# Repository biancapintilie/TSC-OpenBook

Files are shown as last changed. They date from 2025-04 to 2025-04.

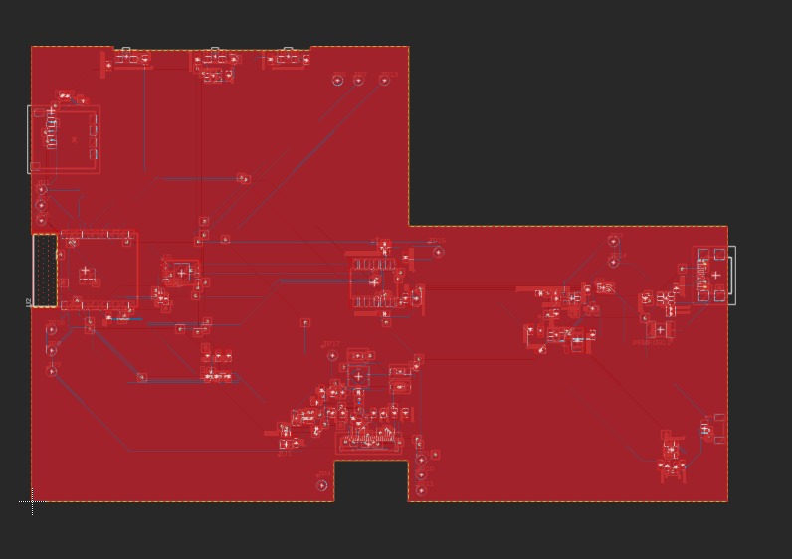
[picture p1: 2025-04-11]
Images/openbook_pcb_top.jpg

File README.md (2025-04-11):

# OpenBook

## Descriere
OpenBook este un dispozitiv portabil bazat pe microcontrollerul ESP32-C6, proiectat pas cu pas, incepand cu schema componentelor, apoi schema electrica si in final modelul 3D al acestuia, urmarind schemele si indrumarile oferite in enuntul temei.
Pentru schematic am descarcat libraria din enunt si am folosit piesele de acolo pentru a realiza componentele si le-am asezat in frame exact ca in exemplul din enunt.
La partea de PCB am amplasat piesele dupa desenul dat, urmand masuratorile exacte, iar rutarea am facut-o folosind combinatia intre autorute si rute manuale pentru evitarea erorilor, fiind nevoita sa mai misc piesele incat sa pot ruta cat mai ok. Apoi am facut planurile de masa, atat pentru top cat si pentru bottom.
In final, am cautat modelul 3D pentru fiecare piesa pentru a-l adauga la forma 3D finala a dispozitivului, impreuna cu carcasa acestuia.

## Hardware

### **1. Microcontroller U2 – ESP32-C6-WROOM-1-N8**
#### - Modul principal de procesare, cu:
 - Procesor RISC-V single-core, 160 MHz
 - 	Wi-Fi 6 și Bluetooth 5.0
 - 	8 MB flash
 - 	Alimentare: 3.3V
#### - Conexiuni principale:
- SPI (pentru e-paper și microSD)
- I2C (pentru RTC și senzori)
- GPIO (pentru butoane, LED-uri, control power)

#### - Pini folosiți ESP32-C6:
| Semnal | Pin ESP32	| Funcție |
|---|---|---|
| MOSI | GPIO10 |	Date spre e-paper |
| SCK | GPIO9 |	Ceas SPI |
| CS | GPIO8 | Chip Select |
| DC | GPIO7 | Data/Command |
| RST | GPIO5 |	Reset display |
| BUSY | GPIO6 | Status afișaj |

### 2. Afișaj e-paper J1 – FH34SRJ-24S-0.5SH
- Afișaj conectat prin SPI
- Condensatori de filtrare în jurul e-paper:
- EPD_C1–C12: 0.1–1uF (filtrare alimentare și stabilizare semnal)
- MOSFET: Q3 – SI1308EDL (pentru comutarea alimentării e-paperului)

### 3. Memorie și stocare U1 – W25Q512JVEIQ
- 64MB NOR Flash SPI
- Pentru stocarea fișierelor locale, fonturi, etc.
microSD (SPI shared):
- Partajat cu SPI-ul e-paper
- CS separat (ex: GPIO15)

### 4. Alimentare & management baterie Li-Po 3.7V
#### - Încărcare:
- MCP73831 (U MCP73831) – încărcare baterie prin USB
- Diodă protecție: D3–D5 (MBR0530)
#### - Monitorizare baterie:
- MAX17048 (U4) – Fuel Gauge via I2C
- Divizor rezistiv: R1_BAT, R2_BAT
- ADC ESP32: GPIO1
#### - Condensatori alimentare:
- C1_BAT, C2_BAT, C3, etc. – diverse capacități pentru filtrare și stabilizare (4.7uF – 100uF)

### 5. Ceas în timp real (RTC) U3 – DS3231SN
- RTC cu I2C, extrem de precis
- Backup pe supercapacitor (C10_SUPERCAP)
- Conexiune I2C: GPIO21 (SDA), GPIO22 (SCL)

### 6. Senzor SENSOR2 – BME680
- Senzor de mediu: temperatură, presiune, umiditate, COV
- Interfață I2C (partajat cu RTC)

### 7. Interfață utilizator
#### - Butoane fizice:
- BOOT_BUTTON, RESET_BUTTON, CHANGE_BUTTON
- Conectate pe GPIO2, GPIO3, GPIO4 (cu pull-up R_RESET, R_CHANGE etc.)
#### - LED RGB pentru feedback:
- CHG_LED – conectat la GPIO18 (PWM)

### 8. Protecție și filtrare
- D1 – USBLC6-2SC6Y – protecție ESD pe linia USB
- PGB1010603MR (D6, D8–D12) – protecție la supratensiune
- PFMF.050.1 – Varistor pentru liniile de alimentare

### 9. Alte circuite pasive
- Filtru LC pe alimentare display: L1 – 68uH, C7, C8
- Diverse rezistențe pull-up/down, limitare curent, etc.:
- R1–R10, R_BOOT, R_PWRUSB, R_CAPACITOR etc.
- Majoritatea în format 0402

### 10. Test Points & Debug
- TP1–TP17: puncte de test pentru semnale critice
- UART debug: GPIO43 (TX), GPIO44 (RX) – pentru încărcare firmware și debug

### Carcasă și design fizic
- PCB în format compact, optimizat pentru portabilitate
- Carcasă printată 3D
- Acces facil la conectorul USB-C (J2) pentru încărcare

## Schema Bloc


## Bill Of Materials

| Componenta | Link | Datasheet |
|---|---|---|
| Capacitor 0402 | [Model](https://componentsearchengine.com/part-view/CC0402MRX5R5BB106/YAGEO) | [Datasheet](https://componentsearchengine.com/Datasheets/2/CC0402MRX5R5BB106.pdf) |
| CPH3225A | [Model](https://www.snapeda.com/parts/CPH3225A/Seiko+Instruments/view-part/?ref=eda) | [Datasheet](https://www.snapeda.com/parts/CPH3225A/Seiko+Instruments/view-part/?ref=eda) |
| RCL 3528 | [Model](https://www.snapeda.com/parts/TAJB475K025RNJ/AVX/view-part/?ref=dk&t=capacitor%203528&con_ref=None) | [Datasheet](https://s3.amazonaws.com/snapeda/datasheet/TAJB475K025RNJ_AVX.pdf) |
| Resistor 0402 | [Model](https://componentsearchengine.com/part-view/R0402%201%25%20100%20K%20(RC0402FR-07100KL)/YAGEO) | [Datasheet](https://www.yageo.com/upload/media/product/products/datasheet/rchip/PYu-RC_Group_51_RoHS_L_12.pdf) |
| Dioda MBR0530 | [Model](https://eu.mouser.com/ProductDetail/KYOCERA-AVX/SD0805S020S1R0?qs=jCA%252BPfw4LHbpkAoSnwrdjw%3D%3D) | [Datasheet](https://ro.mouser.com/datasheet/2/40/schottky-3165252.pdf) |
| Dioda PGB1010603MR | [Model](https://www.snapeda.com/parts/PGB1010603MR/Littelfuse/view-part/?ref=eda) | [Datasheet](https://www.snapeda.com/parts/PGB1010603MR/Littelfuse%20Inc./datasheet/) |
| Buton | [Model](https://industry.panasonic.com/global/en/products/control/switch/light-touch/number/evqpuj02k) | [Datasheet](https://industry.panasonic.com/global/en/downloads?tab=catalog&small_g_cd=203&part_no=EVQPUJ02K) |
| LED 0603 | [Model](https://www.snapeda.com/parts/KP-1608SURCK/Kingbright/view-part/?ref=search&t=LED%200603) | [Datasheet](https://www.snapeda.com/parts/KP-1608SURCK/Kingbright/datasheet/) |
| Sensor BME680 | [Model](https://www.digikey.ro/en/models/7401317) | [Datasheet](https://www.bosch-sensortec.com/media/boschsensortec/downloads/datasheets/bst-bme680-ds001.pdf) |
| SJ | [Model](https://grabcad.com/library/solder-jumpers-1) | [Datasheet](https://grabcad.com/library/solder-jumpers-1) |
| ESP32C6 | [Model](https://ro.mouser.com/ProductDetail/EPCOS-TDK/B72520T0350K062?qs=dEfas%2FXlABIszF52uu7vrg%3D%3D) | [Datasheet](https://www.snapeda.com/parts/RC0603JR-070RL/Yageo/datasheet/) |
| FH34SRJ-24S-0.5SH (J1) | [Model](https://www.snapeda.com/parts/FH34SRJ-24S-0.5SH(99)/Hirose/view-part/) | [Datasheet](https://www.snapeda.com/parts/FH34SRJ-24S-0.5SH(99)/Hirose%20Connector/datasheet/) |
| USB4110-GF-A (J2) | [Model](https://componentsearchengine.com/part-view/USB4110-GF-A/GCT%20(GLOBAL%20CONNECTOR%20TECHNOLOGY)) | [Datasheet](https://gct.co/files/drawings/usb4110.pdf) |
| QWIIC Connector (J3) | [Model](https://www.snapeda.com/parts/PRT-14417/SparkFun/view-part/) | [Datasheet](https://www.snapeda.com/parts/PRT-14417/SparkFun%20Electronics/datasheet/) |
| 112A-TAAR-R03 (J4)| [Model](https://www.snapeda.com/parts/112A-TAAR-R03/Attend/view-part/) | [Datasheet](https://www.snapeda.com/parts/112A-TAAR-R03/Attend/datasheet/) |
| 744043680 (L1)| [Model](https://ro.mouser.com/ProductDetail/Wurth-Elektronik/744043680?qs=PGXP4M47uW6VkZq%252BkzjrHA%3D%3D) | [Datasheet](https://www.we-online.com/components/products/datasheet/744043680.pdf) |
| DMG2305UX-7 (Q1, Q2) | [Model](https://componentsearchengine.com/part-view/DMG2305UX-7/Diodes%20Incorporated) | [Datasheet](https://www.snapeda.com/parts/SI1308EDL-T1-GE3/Vishay%20Siliconix/datasheet/) |
| SI1308EDL-T1-GE3 (Q3) | [Model](https://componentsearchengine.com/part-view/SI1308EDL-T1-GE3/Vishay) | [Datasheet](https://www.snapeda.com/parts/SI1308EDL-T1-GE3/Vishay%20Siliconix/datasheet/) |
| W25Q512JVEIQ (U1) | [Model](https://www.snapeda.com/parts/W25Q512JVEIQ/Winbond+Electronics/view-part/?ref=eda) | [Datasheet](https://www.winbond.com/resource-files/W25Q512JV%20SPI%20RevB%2006252019%20KMS.pdf) |
| ESP32C6 WROOM-1-N8 (U2) | [Model](https://www.snapeda.com/parts/ESP32-C6-WROOM-1-N8/Espressif+Systems/view-part/?ref=eda) | [Datasheet](https://www.snapeda.com/parts/ESP32-C6-WROOM-1-N8/Espressif+Systems/view-part/?ref=eda) |
| DS3231SN (U3) | [Model](https://www.snapeda.com/parts/DS3231SN%23/Analog+Devices/view-part/?ref=eda) | [Datasheet](https://www.snapeda.com/parts/DS3231SN%23/Analog%20Devices/datasheet/) |
| MAX17048G+T10 (U4) | [Model](https://www.snapeda.com/parts/MAX17048G+T10/Analog+Devices/view-part/?ref=eda) | [Datasheet](https://www.snapeda.com/parts/MAX17048G+T10/Analog%20Devices/datasheet/) |
| MCP73831 Power Management (U5) | [Model](https://www.snapeda.com/parts/MCP73831T-2ACI/OT/Microchip/view-part/) | [Datasheet](https://www.snapeda.com/parts/MCP73831T-2ACI/OT/Microchip/datasheet/) |
| BD5229G-TR (IC1) | [Model](https://www.digikey.ee/en/models/658502) | [Datasheet](https://fscdn.rohm.com/en/products/databook/datasheet/ic/power/voltage_detector/bd52xxg-e.pdf) |
| XC6220A331MR-G (IC4) | [Model](https://componentsearchengine.com/part-view/XC6220A331MR-G/Torex) | [Datasheet](https://product.torexsemi.com/system/files/series/xc6220.pdf) |

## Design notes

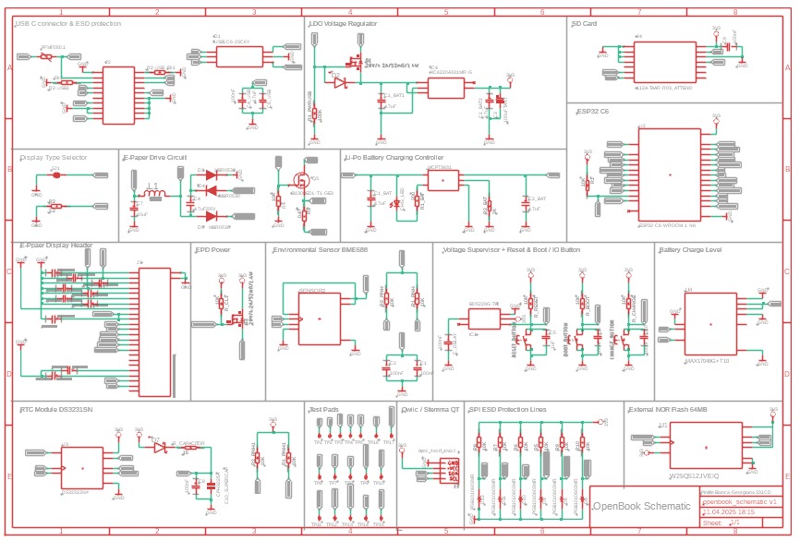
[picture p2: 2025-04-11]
Images/openbook_schematic.jpg

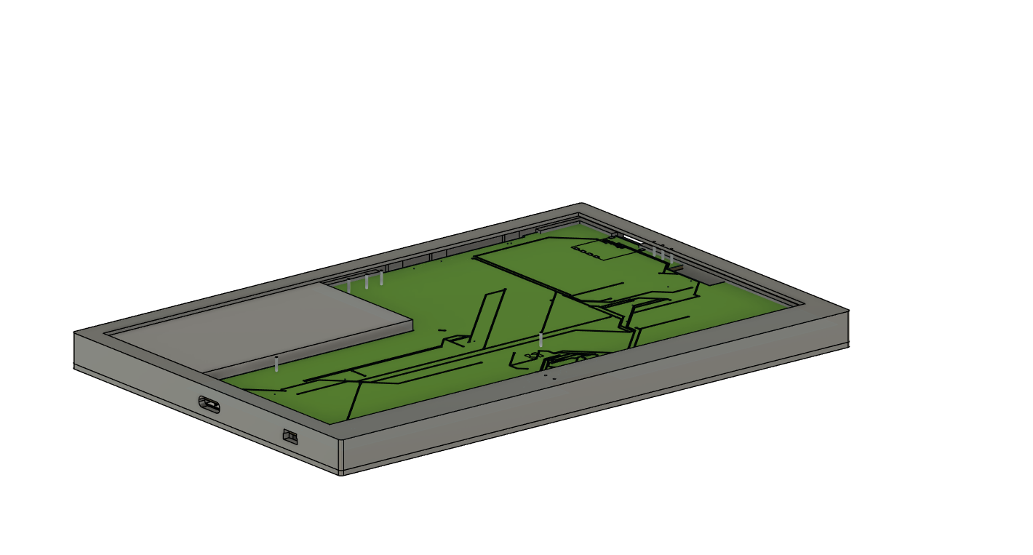
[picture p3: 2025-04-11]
Images/withbattery.png

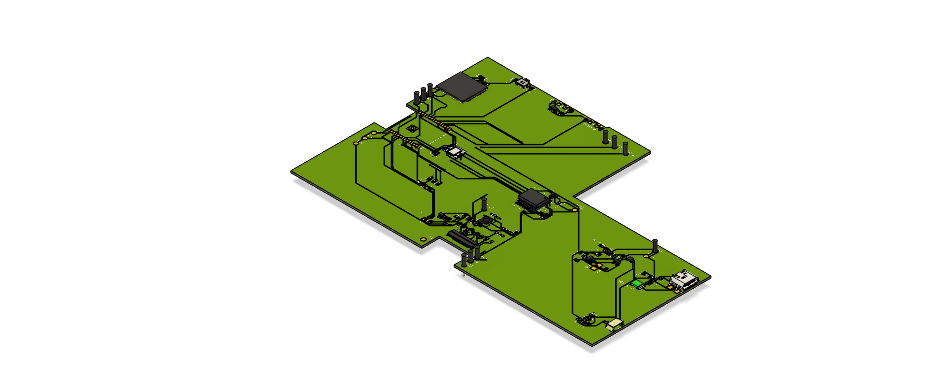
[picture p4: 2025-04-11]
Images/3dpcb.png

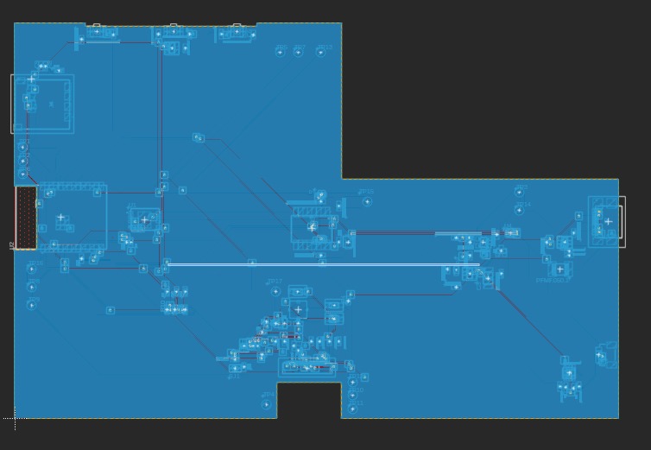
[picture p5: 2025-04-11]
Images/openbook_pcb_bottom.jpg

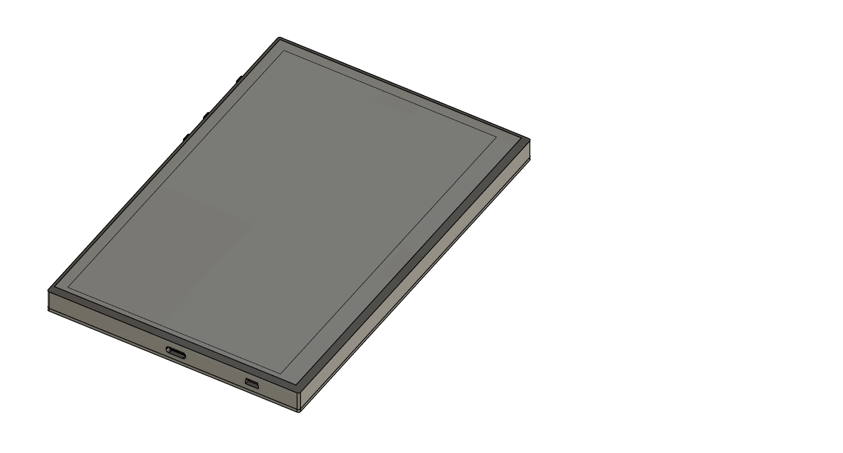
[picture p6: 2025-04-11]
Images/with display.png

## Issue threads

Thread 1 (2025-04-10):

Layer gresit in Schematic

Geox644, 2025-04-10:
Am observat ca in Schematic, denumirile componentelor si liniile de ghidaj din interiorul frame-ului sunt plasate pe layer-ul Nets, asa cum se poate vedea si in imaginea de mai jos.

Acestea ar fi trebuit puse pe layer-ul Info, cum sunt puse si in Schematic-ul de referinta.

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

Closed 2025-04-11.

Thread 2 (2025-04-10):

Dimensiuni incorecte pentru traseele de putere

Geox644, 2025-04-10:
Am observat ca traseele de putere (ex: VCC, VUSB, VBUS, 3V3, etc.) nu au fost rutate folosind latimea de 0.3 mm, asa cum este specificat in cerinta.

In plus, pare ca ai lucrat in mil in loc de mm, iar asta poate duce la neconcordante in latimea traseelor.

Dupa ce schimbi valoarea in mm din grid settings, ai sa vezi ca acum ai latimea de 0.127mm, pe care trebuie sa o modifici in 0.3mm pentru traseele de putere.

-  Latimea curenta: 0.127mm
-  Latimea minima ceruta trasee de putere: 0.3mm

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

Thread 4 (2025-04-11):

Lipsa model 3d componente

Geox644, 2025-04-11:
Lipsesc mai multe modele 3d ale componentelor de pe placuta, precum:

- rezistente
- condenasatoare
- TP-uri
- J2, J3, J4
- butoane
- diode
- U4
- sensor2
- Q1, Q2
- IC1

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

biancapintilie, 2025-04-11:
intr-adevar nu erau, insa dupa modificari le-am pus pe toate, dar nu stiu de ce nu apar pe pcb-ul 3d

Closed 2025-04-11.

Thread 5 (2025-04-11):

Pozitionare gresita componente 3d

Geox644, 2025-04-11:
## Componenta U1
- Modelul 3d nu este tocmai corect plasat pe placuta. Componenta nu este aliniata bine peste pad-uri, asa cum se vede si in imaginea de mai jos.

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

## Analog  componenta MCP73831

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

Closed 2025-04-11.

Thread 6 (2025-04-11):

Spatii goale in planul GND

Geox644, 2025-04-11:
Exista goluri in planul tau GND. Pentru a rezolva problema, trebuie adaugate via-uri legate la GND in locurile libere corespunzatoare (fara a suprapune alte trasee sau pad-uri).

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

Closed 2025-04-11.

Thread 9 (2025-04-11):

Readme incomplet

Geox644, 2025-04-11:
## Lipsa tabel BOM
Lipseste din Readme tabelul cu componentele pe care le-ai folosit, impreuna cu link-uri catre locul de unde le-ai luat si link catre datasheet-ul lor.

### Exemplu tabel BOM
Componenta | Link | Datasheet
-- | -- | --
BUTTON | [Model](https://industry.panasonic.com/global/en/products/control/switch/light-touch/number/evqpuj02k) | [Datasheet](https://industry.panasonic.com/global/en/downloads?tab=catalog&small_g_cd=203&part_no=EVQPUJ02K)
Componenta 2 | link | datasheet
Componenta 3 | link | datasheet

## Lipsa diagrama bloc
Link model diagrama [aici.](https://docs.google.com/drawings/d/1UpxRyJNfczJHhNRvWdeb5kh_7IEUy5173odk93W_GSA/edit)

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

## Recomandare 🤗

➡️ Iti recomand ca pentru un aspect mai frumos si lizibil in README, sa pui informatiile structurate pe bullet point-uri, iar titlurile sa le scrii mai mari, pentru a iesi in evidenta.

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

➡️ De exemplu, aici la partea de Hardware, asa cum ai scris tu, e putin greu de urmarit si cred ca ar fi mai usor de citit daca ar fi scris in stilul acesta:

## Hardware

#### 1. Microcontroller U2 – ESP32-C6-WROOM-1-N8 • Modul principal de procesare, cu:
- Procesor RISC-V single-core, 160 MHz o Wi-Fi 6
- Bluetooth 5.0
- 8 MB flash
- Alimentare: 3.3V
- Conexiuni principale:  SPI (pentru e-paper și microSD), I2C (pentru RTC și senzori), GPIO (pentru butoane, LED-uri, control power)

Closed 2025-04-11.

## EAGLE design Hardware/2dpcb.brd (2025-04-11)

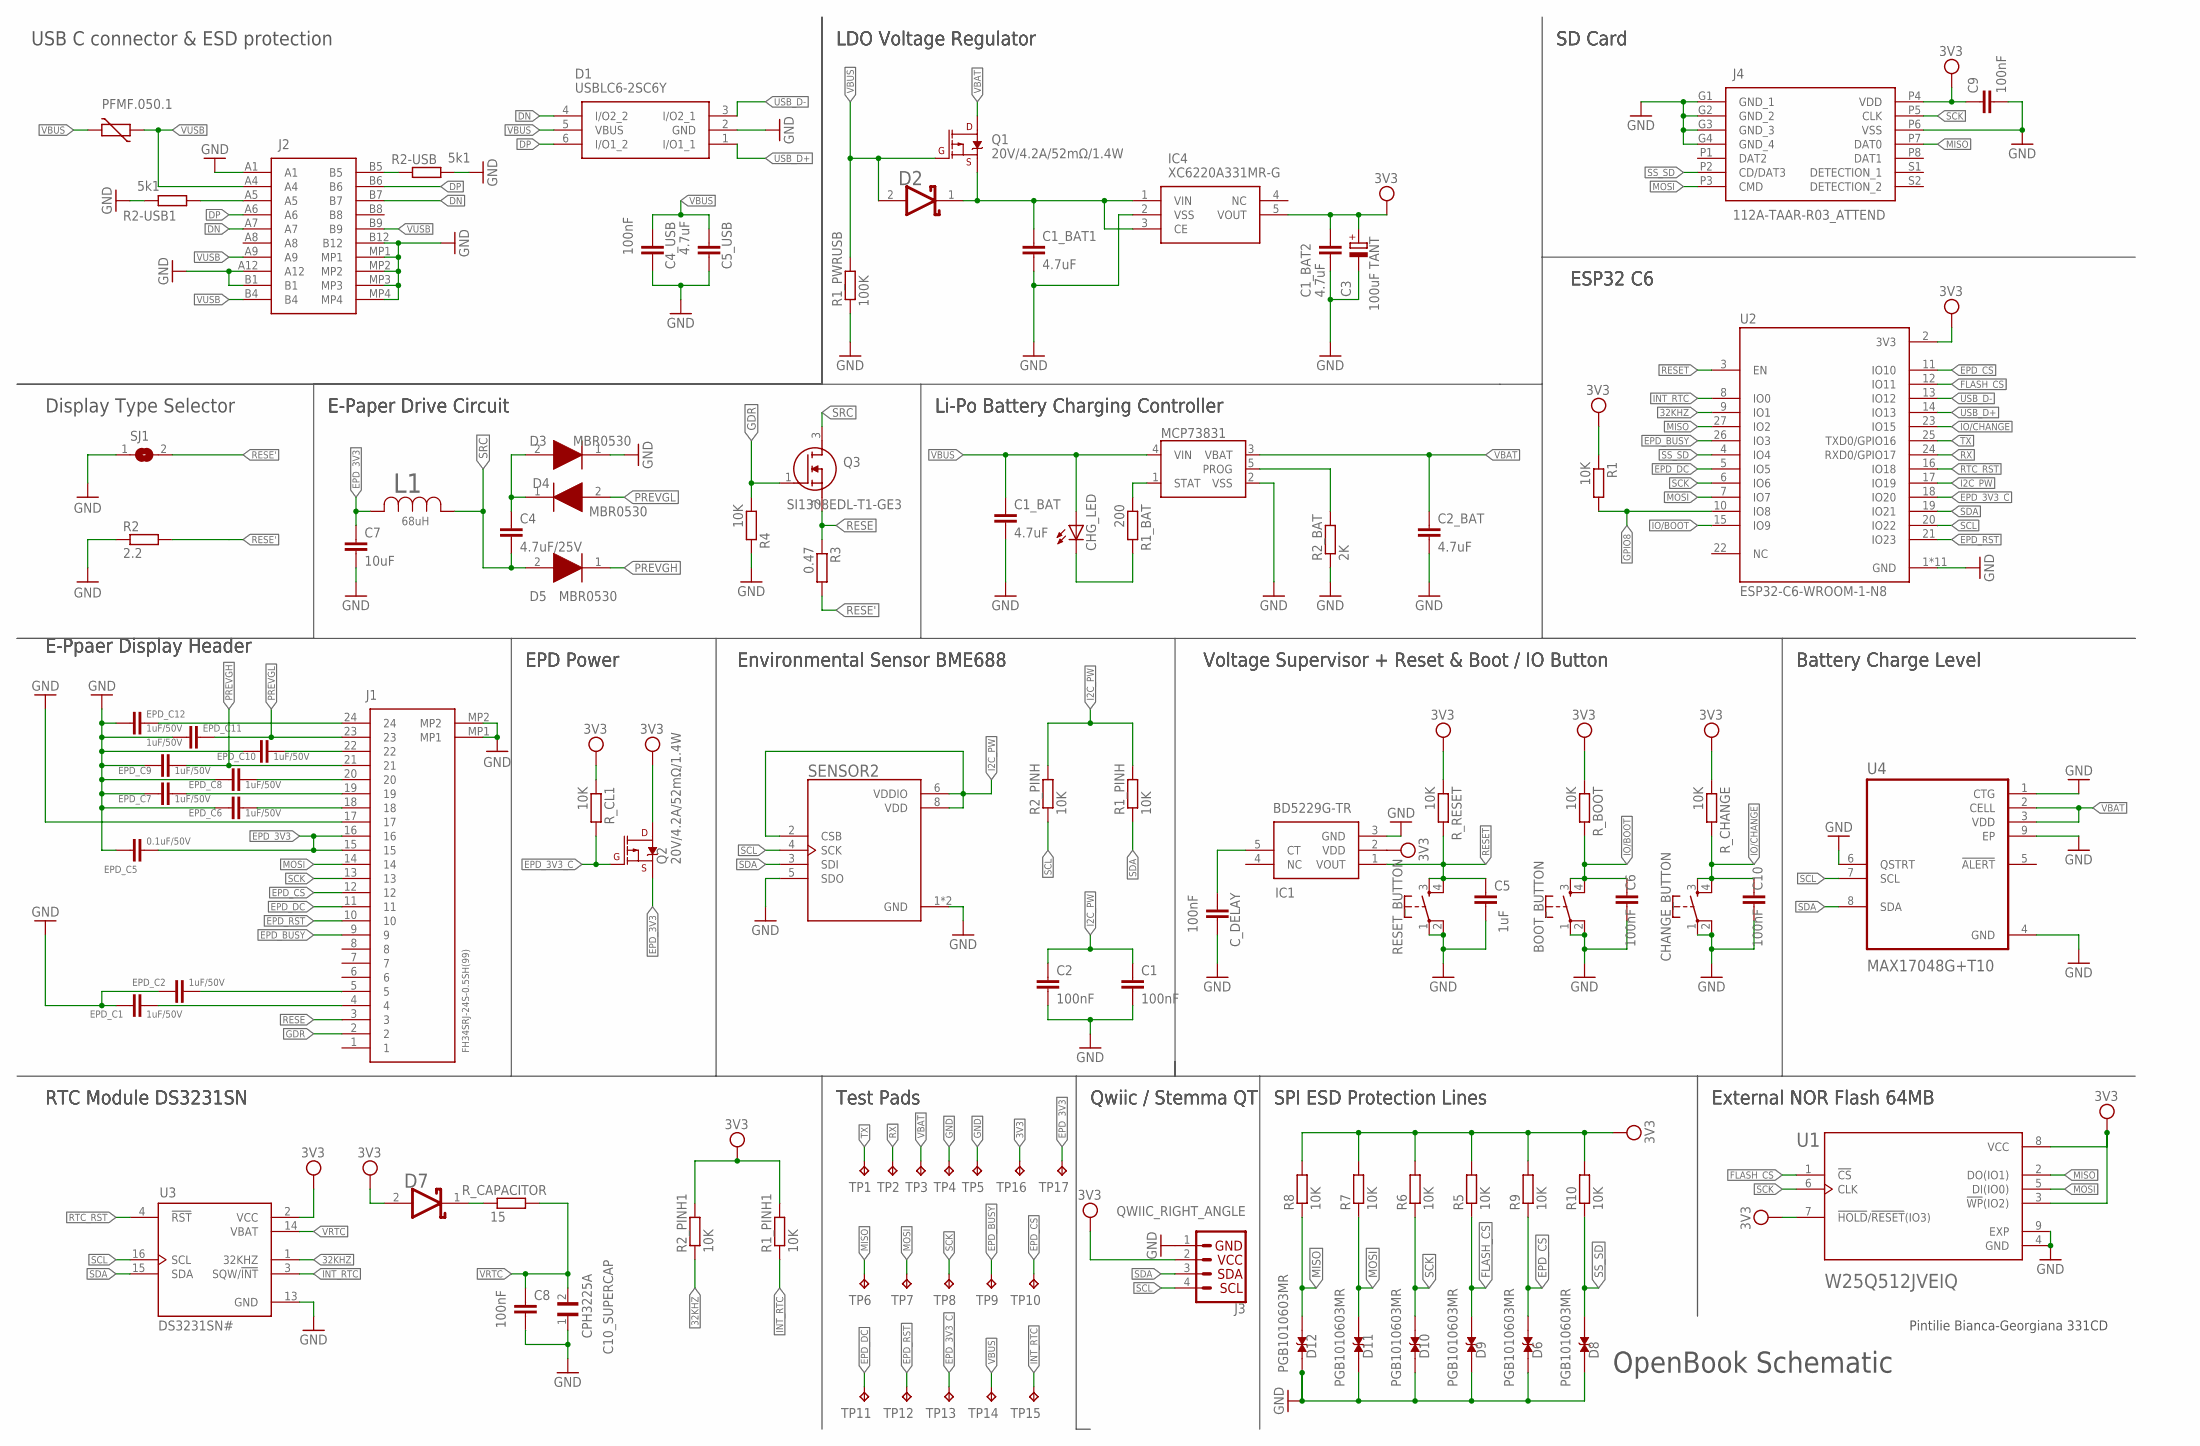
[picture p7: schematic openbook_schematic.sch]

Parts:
BOOT_BUTTON: BUTTON_CUSYOMV1; MYBUTTON
C1, C2, C4_USB, C6, C8, C9, C10: 100nF; EAGLE-LTSPICE_C0402
C1_BAT, C1_BAT1, C1_BAT2, C2_BAT, C5_USB: 4.7uF; EAGLE-LTSPICE_C0402
C3: 100uF TANT; RCL_CT3528
C4: 4.7uF/25V; EAGLE-LTSPICE_C0402
C5: 1uF; EAGLE-LTSPICE_C0402
C7: 10uF; EAGLE-LTSPICE_C0402
C10_SUPERCAP: CPH3225A; CAPCP3225X100N
CHANGE_BUTTON: BUTTON_CUSYOMV1; MYBUTTON
CHG_LED: ADAFRUIT_LEDCHIP-LED0603; ADAFRUIT_CHIP-LED0603
C_DELAY: 100nF; EAGLE-LTSPICE_C0402
D1: USBLC6-2SC6Y; SOT95P280X145-6N
D2, D7: ESP32_WROVER_AVX---SD0805S020S1R0_AVX_SD0805S020S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; ESP32_WROVER_AVX---SD0805S020S1R0_AVX_SD0805S020S1R0_0
D3, D4, D5: MBR0530; SOD3716X135N
D6, D8, D9, D10, D11, D12: PGB1010603MR; DIOC1608X36N
EPD_C1, EPD_C2, EPD_C6, EPD_C7, EPD_C8, EPD_C9, EPD_C10, EPD_C11, EPD_C12: 1uF/50V; ESP32_WROVER_EAGLE-LTSPICE_C0402
EPD_C5: 0.1uF/50V; ESP32_WROVER_EAGLE-LTSPICE_C0402
IC1: BD5229G-TR; SOT95P280X125-5N
IC4: XC6220A331MR-G; SOT95P280X120-5N
J1: FH34SRJ-24S-0.5SH_99_; FH34SRJ24S05SH99
J2: SAMACSYS_PARTS_USB4110-GF-A; SAMACSYS_PARTS_USB4110GFA
J3: QWIIC_RIGHT_ANGLE; JST04_1MM_RA
J4: 112A-TAAR-R03_ATTEND; 112ATAARR03ATTEND
L1: 68uH; IND_4828-WE-TPC_WRE
MCP73831: ESP32_WROVER_SPARKFUN-IC-POWER_MCP73831; ESP32_WROVER_SPARKFUN-IC-POWER_SOT23-5
PFMF.050.1: ESP32C6_VARISTORCN1812; ESP32C6_VARISTOR_CT/CN1812
Q1, Q2: 20V/4.2A/52mΩ/1.4W; ESP32_WROVER_SPARKFUN-DISCRETESEMI_SOT23-3
Q3: SI1308EDL-T1-GE3; SOT65P210X110-3N
R1, R1_PINH, R1_PINH1, R2_PINH, R2_PINH1, R4, R5, R6, R7, R8, R9, R10: 10K; ESP32_WROVER_EAGLE-LTSPICE_R0402
R1_BAT: 200; ESP32_WROVER_EAGLE-LTSPICE_R0402
R1_PWRUSB: 100K; ESP32_WROVER_EAGLE-LTSPICE_R0402
R2: 2.2; ESP32_WROVER_EAGLE-LTSPICE_R0402
R2-USB, R2-USB1: 5k1; ESP32_WROVER_EAGLE-LTSPICE_R0402
R2_BAT: 2K; ESP32_WROVER_EAGLE-LTSPICE_R0402
R3: 0.47; ESP32_WROVER_EAGLE-LTSPICE_R0402
RESET_BUTTON: BUTTON_CUSYOMV1; MYBUTTON
R_BOOT: 10K; ESP32_WROVER_EAGLE-LTSPICE_R0402
R_CAPACITOR: 15; ESP32_WROVER_EAGLE-LTSPICE_R0402
R_CHANGE: 10K; ESP32_WROVER_EAGLE-LTSPICE_R0402
R_CL1: 10K; ESP32_WROVER_EAGLE-LTSPICE_R0402
R_RESET: 10K; ESP32_WROVER_EAGLE-LTSPICE_R0402
SENSOR2: ESP32_WROVER_BME680_BME680; ESP32_WROVER_BME680_PSON80P300X300X100-8N
SJ1: SJ
TP1, TP2, TP3, TP4, TP5, TP6, TP7, TP8, TP9, TP10, TP11, TP12, TP13, TP14, TP15, TP16, TP17: TPTP20R; TP20R
U1: W25Q512JVEIQ; SON127P600X800X80-9N
U2: ESP32-C6-WROOM-1-N8; XCVR_ESP32-C6-WROOM-1-N8
U3: DS3231SN#; SOIC127P1032X265-16N
U4: MAX17048G+T10; SON50P200X200X80-9N

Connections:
3V3: C1_BAT2.1, C3.+, C9.1, D7.2 (ANODE), IC1.2 (VDD), IC4.5 (VOUT), J3.2, J4.P4 (VDD), Q2.3 (D), R1.1, R1_PINH1.2, R2_PINH1.2, R5.2, R6.2, R7.2, R8.2, R9.2, R10.2, R_BOOT.1, R_CHANGE.1, R_CL1.1, R_RESET.1, TP16.TP, U1.3 (!WP!(IO2)), U1.7 (!HOLD!/!RESET!(IO3)), U1.8 (VCC), U2.2 (3V3), U3.2 (VCC)
32KHZ: R2_PINH1.1, U2.9 (IO1), U3.1 (32KHZ)
DN: D1.4 (I/O2_2), J2.A7, J2.B7
DP: D1.6 (I/O1_2), J2.A6, J2.B6
EPD_3V3: C7.1, EPD_C5.1, J1.15, J1.16, L1.2, Q2.2 (S), TP17.TP
EPD_3V3_C: Q2.1 (G), R_CL1.2, TP13.TP, U2.18 (IO20)
EPD_BUSY: J1.9, TP9.TP, U2.26 (IO3)
EPD_CS: D6.2, J1.12, R9.1, TP10.TP, U2.11 (IO10)
EPD_DC: J1.11, TP11.TP, U2.5 (IO5)
EPD_RST: J1.10, TP12.TP, U2.21 (IO23)
FLASH_CS: D9.2, R5.1, U1.1 (!CS), U2.12 (IO11)
GDR: J1.2, Q3.1 (G), R4.1
GND: BOOT_BUTTON.1, BOOT_BUTTON.2, C1.2, C1_BAT.2, C1_BAT1.2, C1_BAT2.2, C2.2, C2_BAT.2, C3.-, C4_USB.2, C5.2, C5_USB.2, C6.2, C7.2, C8.2, C9.2, C10.2, C10_SUPERCAP.1, CHANGE_BUTTON.1, CHANGE_BUTTON.2, C_DELAY.2, D1.2 (GND), D3.1 (K), D6.1, D8.1, D9.1, D10.1, D11.1, D12.1, EPD_C1.2, EPD_C2.2, EPD_C5.2, EPD_C6.2, EPD_C7.2, EPD_C8.2, EPD_C9.2, EPD_C10.2, EPD_C11.2, EPD_C12.2, IC1.3 (GND), IC4.2 (VSS), J1.17, J1.MP1, J1.MP2, J2.A1, J2.A12, J2.B1, J2.B12, J2.MP1, J2.MP2, J2.MP3, J2.MP4, J3.1, J4.G1 (GND_1), J4.G2 (GND_2), J4.G3 (GND_3), J4.G4 (GND_4), J4.P6 (VSS), MCP73831.2 (VSS), R1_PWRUSB.1, R2.1, R2-USB.2, R2-USB1.1, R2_BAT.1, R4.2, RESET_BUTTON.1, RESET_BUTTON.2, SENSOR2.1 (GND), SENSOR2.5 (SDO), SENSOR2.7 (GND), SJ1.1, TP4.TP, TP5.TP, U1.4 (GND), U1.9 (EXP), U2.1 (GND), U2.28 (GND), U2.29_1 (GND), U2.29_2 (GND), U2.29_3 (GND), U2.29_4 (GND), U2.29_5 (GND), U2.29_6 (GND), U2.29_7 (GND), U2.29_8 (GND), U2.29_9 (GND), U3.13 (GND), U4.1 (CTG), U4.4 (GND), U4.6 (QSTRT), U4.9 (EP)
GPIO8: R1.2, U2.10 (IO8)
I2C_PW: C1.1, C2.1, R1_PINH.2, R2_PINH.2, SENSOR2.2 (CSB), SENSOR2.6 (VDDIO), SENSOR2.8 (VDD), U2.17 (IO19)
INT_RTC: R1_PINH1.1, TP15.TP, U2.8 (IO0), U3.3 (SQW/!INT)
IO/BOOT: BOOT_BUTTON.3, BOOT_BUTTON.4, C6.1, R_BOOT.2, U2.15 (IO9)
IO/CHANGE: C10.1, CHANGE_BUTTON.3, CHANGE_BUTTON.4, R_CHANGE.2, U2.23 (IO15)
MISO: D12.2, J4.P7 (DAT0), R8.1, TP6.TP, U1.2 (DO(IO1)), U2.27 (IO2)
MOSI: D11.2, J1.14, J4.P3 (CMD), R7.1, TP7.TP, U1.5 (DI(IO0)), U2.7 (IO7)
unnamed: EPD_C10.1, J1.22
unnamed: EPD_C8.1, J1.20
unnamed: EPD_C6.1, J1.18
unnamed: C4.1, D3.2 (A), D4.1 (K)
unnamed: EPD_C7.1, J1.19
unnamed: EPD_C1.1, J1.4
unnamed: EPD_C2.1, J1.5
unnamed: J2.B5, R2-USB.1
unnamed: J2.A5, R2-USB1.2
unnamed: EPD_C12.1, J1.24
unnamed: C1_BAT1.1, D2.1 (CATHODE), IC4.1 (VIN), IC4.3 (CE), Q1.2 (S)
unnamed: MCP73831.1 (STAT), R1_BAT.1
unnamed: CHG_LED.C, R1_BAT.2
unnamed: MCP73831.5 (PROG), R2_BAT.2
unnamed: C_DELAY.1, IC1.5 (CT)
unnamed: D7.1 (CATHODE), R_CAPACITOR.1
PREVGH: D5.1 (K), EPD_C9.1, J1.21
PREVGL: D4.2 (A), EPD_C11.1, J1.23
RESE: J1.3, Q3.2 (S), R3.1
RESE': R2.2, R3.2, SJ1.2
RESET: C5.1, IC1.1 (VOUT), RESET_BUTTON.3, RESET_BUTTON.4, R_RESET.2, U2.3 (EN)
RTC_RST: U2.16 (IO18), U3.4 (!RST)
RX: TP2.TP, U2.24 (RXD0/GPIO17)
SCK: D10.2, J1.13, J4.P5 (CLK), R6.1, TP8.TP, U1.6 (CLK), U2.6 (IO6)
SCL: J3.4, R2_PINH.1, SENSOR2.4 (SCK), U2.20 (IO22), U3.16 (SCL), U4.7 (SCL)
SDA: J3.3, R1_PINH.1, SENSOR2.3 (SDI), U2.19 (IO21), U3.15 (SDA), U4.8 (SDA)
SRC: C4.2, D5.2 (A), L1.1, Q3.3 (D)
SS_SD: D8.2, J4.P2 (CD/DAT3), R10.1, U2.4 (IO4)
TX: TP1.TP, U2.25 (TXD0/GPIO16)
USB_D+: D1.1 (I/O1_1), U2.14 (IO13)
USB_D-: D1.3 (I/O2_1), U2.13 (IO12)
VBAT: C2_BAT.1, MCP73831.3 (VBAT), Q1.3 (D), TP3.TP, U4.2 (CELL), U4.3 (VDD)
VBUS: C1_BAT.1, C4_USB.1, C5_USB.1, CHG_LED.A, D1.5 (VBUS), D2.2 (ANODE), MCP73831.4 (VIN), PFMF.050.1.2, Q1.1 (G), R1_PWRUSB.2, TP14.TP
VRTC: C8.1, C10_SUPERCAP.2, R_CAPACITOR.2, U3.14 (VBAT)
VUSB: J2.A4, J2.A9, J2.B4, J2.B9, PFMF.050.1.1

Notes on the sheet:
USB C connector & ESD protection
Display Type Selector
E-Paper Drive Circuit
LDO Voltage Regulator
SD Card
ESP32 C6
Li-Po Battery Charging Controller
E-Ppaer Display Header
EPD Power
Environmental Sensor BME688
Voltage Supervisor + Reset & Boot / IO Button
Battery Charge Level
External NOR Flash 64MB
SPI ESD Protection Lines
Test Pads
Qwiic / Stemma QT
RTC Module DS3231SN
OpenBook Schematic
Pintilie Bianca-Georgiana 331CD

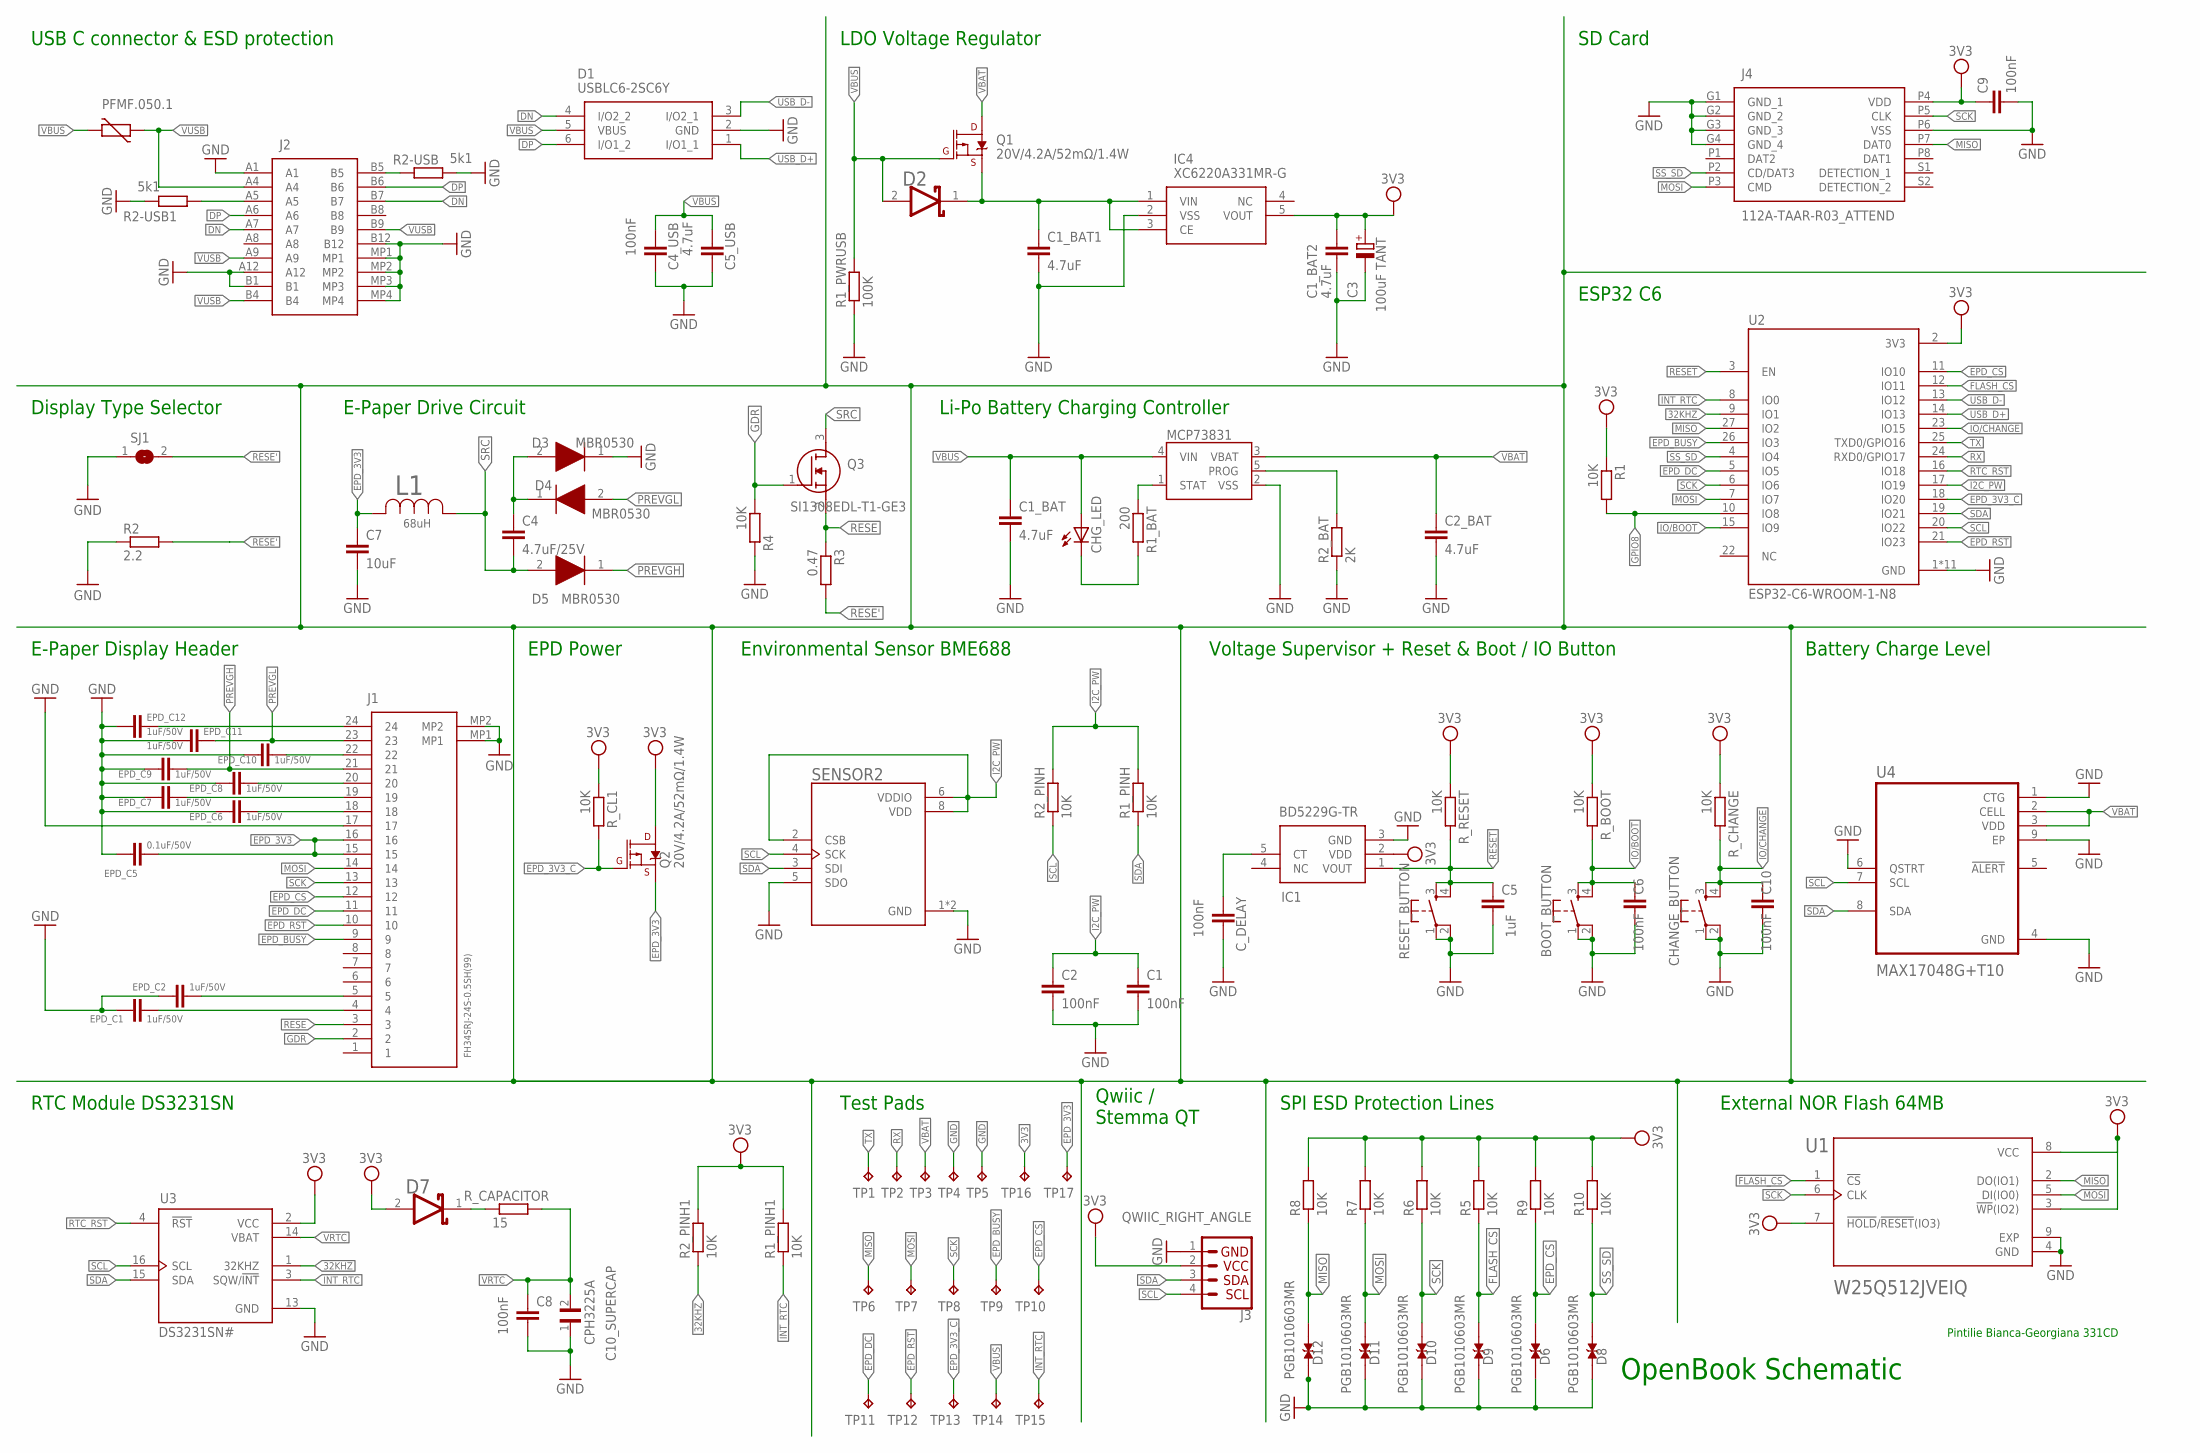
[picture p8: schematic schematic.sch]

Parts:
BOOT_BUTTON: BUTTON_CUSYOMV1; MYBUTTON
C1, C2, C4_USB, C6, C8, C9, C10: 100nF; EAGLE-LTSPICE_C0402
C1_BAT, C1_BAT1, C1_BAT2, C2_BAT, C5_USB: 4.7uF; EAGLE-LTSPICE_C0402
C3: 100uF TANT; RCL_CT3528
C4: 4.7uF/25V; EAGLE-LTSPICE_C0402
C5: 1uF; EAGLE-LTSPICE_C0402
C7: 10uF; EAGLE-LTSPICE_C0402
C10_SUPERCAP: CPH3225A; CAPCP3225X100N
CHANGE_BUTTON: BUTTON_CUSYOMV1; MYBUTTON
CHG_LED: ADAFRUIT_LEDCHIP-LED0603; ADAFRUIT_CHIP-LED0603
C_DELAY: 100nF; EAGLE-LTSPICE_C0402
D1: USBLC6-2SC6Y; SOT95P280X145-6N
D2, D7: ESP32_WROVER_AVX---SD0805S020S1R0_AVX_SD0805S020S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; ESP32_WROVER_AVX---SD0805S020S1R0_AVX_SD0805S020S1R0_0
D3, D4, D5: MBR0530; SOD3716X135N
D6, D8, D9, D10, D11, D12: PGB1010603MR; DIOC1608X36N
EPD_C1, EPD_C2, EPD_C6, EPD_C7, EPD_C8, EPD_C9, EPD_C10, EPD_C11, EPD_C12: 1uF/50V; ESP32_WROVER_EAGLE-LTSPICE_C0402
EPD_C5: 0.1uF/50V; ESP32_WROVER_EAGLE-LTSPICE_C0402
IC1: BD5229G-TR; SOT95P280X125-5N
IC4: XC6220A331MR-G; SOT95P280X120-5N
J1: FH34SRJ-24S-0.5SH_99_; FH34SRJ24S05SH99
J2: SAMACSYS_PARTS_USB4110-GF-A; SAMACSYS_PARTS_USB4110GFA
J3: QWIIC_RIGHT_ANGLE; JST04_1MM_RA
J4: 112A-TAAR-R03_ATTEND; 112ATAARR03ATTEND
L1: 68uH; IND_4828-WE-TPC_WRE
MCP73831: ESP32_WROVER_SPARKFUN-IC-POWER_MCP73831; ESP32_WROVER_SPARKFUN-IC-POWER_SOT23-5
PFMF.050.1: ESP32C6_VARISTORCN1812; ESP32C6_VARISTOR_CT/CN1812
Q1, Q2: 20V/4.2A/52mΩ/1.4W; ESP32_WROVER_SPARKFUN-DISCRETESEMI_SOT23-3
Q3: SI1308EDL-T1-GE3; SOT65P210X110-3N
R1, R1_PINH, R1_PINH1, R2_PINH, R2_PINH1, R4, R5, R6, R7, R8, R9, R10: 10K; ESP32_WROVER_EAGLE-LTSPICE_R0402
R1_BAT: 200; ESP32_WROVER_EAGLE-LTSPICE_R0402
R1_PWRUSB: 100K; ESP32_WROVER_EAGLE-LTSPICE_R0402
R2: 2.2; ESP32_WROVER_EAGLE-LTSPICE_R0402
R2-USB, R2-USB1: 5k1; ESP32_WROVER_EAGLE-LTSPICE_R0402
R2_BAT: 2K; ESP32_WROVER_EAGLE-LTSPICE_R0402
R3: 0.47; ESP32_WROVER_EAGLE-LTSPICE_R0402
RESET_BUTTON: BUTTON_CUSYOMV1; MYBUTTON
R_BOOT: 10K; ESP32_WROVER_EAGLE-LTSPICE_R0402
R_CAPACITOR: 15; ESP32_WROVER_EAGLE-LTSPICE_R0402
R_CHANGE: 10K; ESP32_WROVER_EAGLE-LTSPICE_R0402
R_CL1: 10K; ESP32_WROVER_EAGLE-LTSPICE_R0402
R_RESET: 10K; ESP32_WROVER_EAGLE-LTSPICE_R0402
SENSOR2: ESP32_WROVER_BME680_BME680; ESP32_WROVER_BME680_PSON80P300X300X100-8N
SJ1: SJ
TP1, TP2, TP3, TP4, TP5, TP6, TP7, TP8, TP9, TP10, TP11, TP12, TP13, TP14, TP15, TP16, TP17: TPTP20R; TP20R
U1: W25Q512JVEIQ; SON127P600X800X80-9N
U2: ESP32-C6-WROOM-1-N8; XCVR_ESP32-C6-WROOM-1-N8
U3: DS3231SN#; SOIC127P1032X265-16N
U4: MAX17048G+T10; SON50P200X200X80-9N

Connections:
3V3: C1_BAT2.1, C3.+, C9.1, D7.2 (ANODE), IC1.2 (VDD), IC4.5 (VOUT), J3.2, J4.P4 (VDD), Q2.3 (D), R1.1, R1_PINH1.2, R2_PINH1.2, R5.2, R6.2, R7.2, R8.2, R9.2, R10.2, R_BOOT.1, R_CHANGE.1, R_CL1.1, R_RESET.1, TP16.TP, U1.3 (!WP!(IO2)), U1.7 (!HOLD!/!RESET!(IO3)), U1.8 (VCC), U2.2 (3V3), U3.2 (VCC)
32KHZ: R2_PINH1.1, U2.9 (IO1), U3.1 (32KHZ)
DN: D1.4 (I/O2_2), J2.A7, J2.B7
DP: D1.6 (I/O1_2), J2.A6, J2.B6
EPD_3V3: C7.1, EPD_C5.1, J1.15, J1.16, L1.2, Q2.2 (S), TP17.TP
EPD_3V3_C: Q2.1 (G), R_CL1.2, TP13.TP, U2.18 (IO20)
EPD_BUSY: J1.9, TP9.TP, U2.26 (IO3)
EPD_CS: D6.2, J1.12, R9.1, TP10.TP, U2.11 (IO10)
EPD_DC: J1.11, TP11.TP, U2.5 (IO5)
EPD_RST: J1.10, TP12.TP, U2.21 (IO23)
FLASH_CS: D9.2, R5.1, U1.1 (!CS), U2.12 (IO11)
GDR: J1.2, Q3.1 (G), R4.1
GND: BOOT_BUTTON.1, BOOT_BUTTON.2, C1.2, C1_BAT.2, C1_BAT1.2, C1_BAT2.2, C2.2, C2_BAT.2, C3.-, C4_USB.2, C5.2, C5_USB.2, C6.2, C7.2, C8.2, C9.2, C10.2, C10_SUPERCAP.1, CHANGE_BUTTON.1, CHANGE_BUTTON.2, C_DELAY.2, D1.2 (GND), D3.1 (K), D6.1, D8.1, D9.1, D10.1, D11.1, D12.1, EPD_C1.2, EPD_C2.2, EPD_C5.2, EPD_C6.2, EPD_C7.2, EPD_C8.2, EPD_C9.2, EPD_C10.2, EPD_C11.2, EPD_C12.2, IC1.3 (GND), IC4.2 (VSS), J1.17, J1.MP1, J1.MP2, J2.A1, J2.A12, J2.B1, J2.B12, J2.MP1, J2.MP2, J2.MP3, J2.MP4, J3.1, J4.G1 (GND_1), J4.G2 (GND_2), J4.G3 (GND_3), J4.G4 (GND_4), J4.P6 (VSS), MCP73831.2 (VSS), R1_PWRUSB.1, R2.1, R2-USB.2, R2-USB1.1, R2_BAT.1, R4.2, RESET_BUTTON.1, RESET_BUTTON.2, SENSOR2.1 (GND), SENSOR2.5 (SDO), SENSOR2.7 (GND), SJ1.1, TP4.TP, TP5.TP, U1.4 (GND), U1.9 (EXP), U2.1 (GND), U2.28 (GND), U2.29_1 (GND), U2.29_2 (GND), U2.29_3 (GND), U2.29_4 (GND), U2.29_5 (GND), U2.29_6 (GND), U2.29_7 (GND), U2.29_8 (GND), U2.29_9 (GND), U3.13 (GND), U4.1 (CTG), U4.4 (GND), U4.6 (QSTRT), U4.9 (EP)
GPIO8: R1.2, U2.10 (IO8)
I2C_PW: C1.1, C2.1, R1_PINH.2, R2_PINH.2, SENSOR2.2 (CSB), SENSOR2.6 (VDDIO), SENSOR2.8 (VDD), U2.17 (IO19)
INT_RTC: R1_PINH1.1, TP15.TP, U2.8 (IO0), U3.3 (SQW/!INT)
IO/BOOT: BOOT_BUTTON.3, BOOT_BUTTON.4, C6.1, R_BOOT.2, U2.15 (IO9)
IO/CHANGE: C10.1, CHANGE_BUTTON.3, CHANGE_BUTTON.4, R_CHANGE.2, U2.23 (IO15)
MISO: D12.2, J4.P7 (DAT0), R8.1, TP6.TP, U1.2 (DO(IO1)), U2.27 (IO2)
MOSI: D11.2, J1.14, J4.P3 (CMD), R7.1, TP7.TP, U1.5 (DI(IO0)), U2.7 (IO7)
unnamed: EPD_C10.1, J1.22
unnamed: EPD_C8.1, J1.20
unnamed: EPD_C6.1, J1.18
unnamed: C4.1, D3.2 (A), D4.1 (K)
unnamed: EPD_C7.1, J1.19
unnamed: EPD_C1.1, J1.4
unnamed: EPD_C2.1, J1.5
unnamed: J2.B5, R2-USB.1
unnamed: J2.A5, R2-USB1.2
unnamed: EPD_C12.1, J1.24
unnamed: C1_BAT1.1, D2.1 (CATHODE), IC4.1 (VIN), IC4.3 (CE), Q1.2 (S)
unnamed: MCP73831.1 (STAT), R1_BAT.1
unnamed: CHG_LED.C, R1_BAT.2
unnamed: MCP73831.5 (PROG), R2_BAT.2
unnamed: C_DELAY.1, IC1.5 (CT)
unnamed: D7.1 (CATHODE), R_CAPACITOR.1
PREVGH: D5.1 (K), EPD_C9.1, J1.21
PREVGL: D4.2 (A), EPD_C11.1, J1.23
RESE: J1.3, Q3.2 (S), R3.1
RESE': R2.2, R3.2, SJ1.2
RESET: C5.1, IC1.1 (VOUT), RESET_BUTTON.3, RESET_BUTTON.4, R_RESET.2, U2.3 (EN)
RTC_RST: U2.16 (IO18), U3.4 (!RST)
RX: TP2.TP, U2.24 (RXD0/GPIO17)
SCK: D10.2, J1.13, J4.P5 (CLK), R6.1, TP8.TP, U1.6 (CLK), U2.6 (IO6)
SCL: J3.4, R2_PINH.1, SENSOR2.4 (SCK), U2.20 (IO22), U3.16 (SCL), U4.7 (SCL)
SDA: J3.3, R1_PINH.1, SENSOR2.3 (SDI), U2.19 (IO21), U3.15 (SDA), U4.8 (SDA)
SRC: C4.2, D5.2 (A), L1.1, Q3.3 (D)
SS_SD: D8.2, J4.P2 (CD/DAT3), R10.1, U2.4 (IO4)
TX: TP1.TP, U2.25 (TXD0/GPIO16)
USB_D+: D1.1 (I/O1_1), U2.14 (IO13)
USB_D-: D1.3 (I/O2_1), U2.13 (IO12)
VBAT: C2_BAT.1, MCP73831.3 (VBAT), Q1.3 (D), TP3.TP, U4.2 (CELL), U4.3 (VDD)
VBUS: C1_BAT.1, C4_USB.1, C5_USB.1, CHG_LED.A, D1.5 (VBUS), D2.2 (ANODE), MCP73831.4 (VIN), PFMF.050.1.2, Q1.1 (G), R1_PWRUSB.2, TP14.TP
VRTC: C8.1, C10_SUPERCAP.2, R_CAPACITOR.2, U3.14 (VBAT)
VUSB: J2.A4, J2.A9, J2.B4, J2.B9, PFMF.050.1.1

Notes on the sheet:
USB C connector & ESD protection
LDO Voltage Regulator
SD Card
ESP32 C6
Battery Charge Level
External NOR Flash 64MB
SPI ESD Protection Lines
Qwiic / Stemma QT
Test Pads
RTC Module DS3231SN
Display Type Selector
E-Paper Display Header
E-Paper Drive Circuit
Li-Po Battery Charging Controller
EPD Power
Environmental Sensor BME688
Voltage Supervisor + Reset & Boot / IO Button
OpenBook Schematic
Pintilie Bianca-Georgiana 331CD

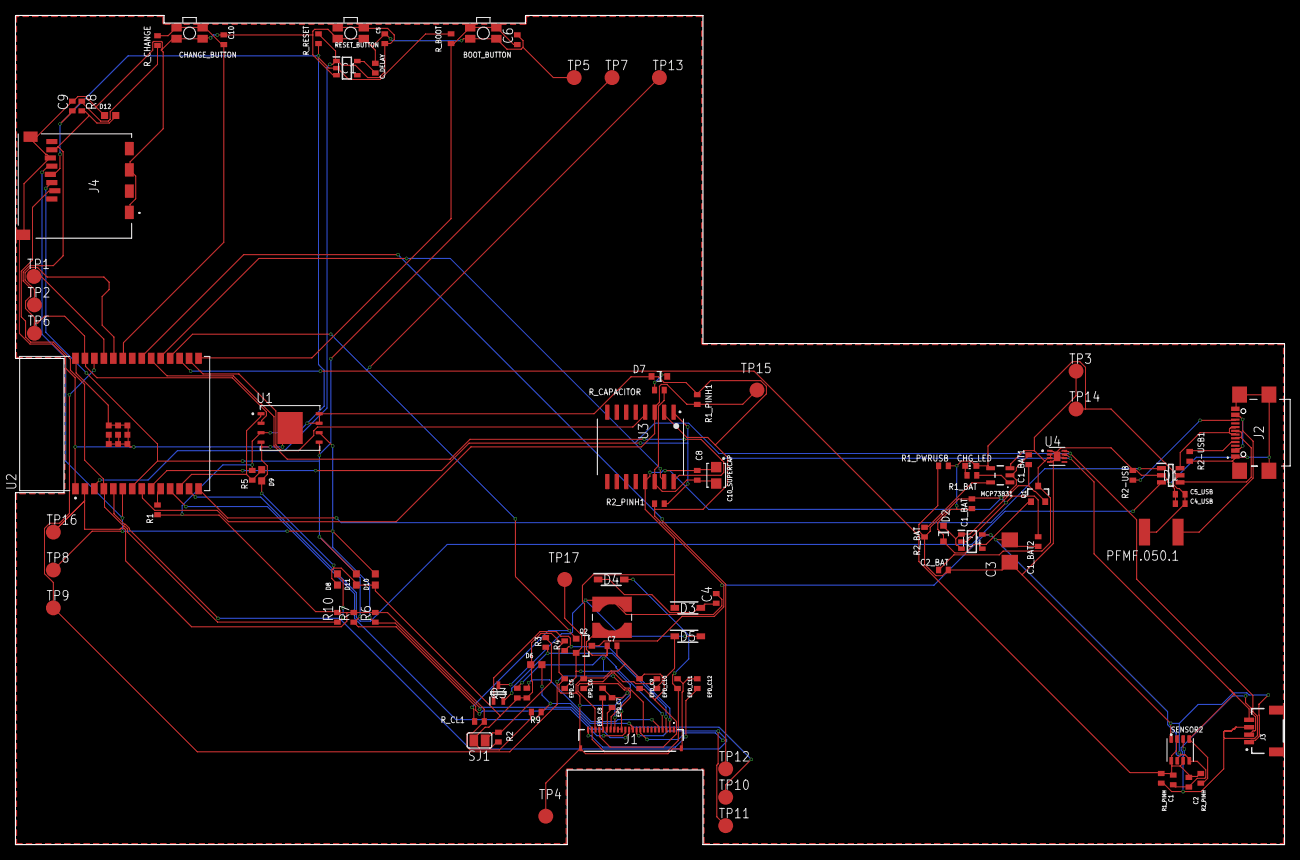
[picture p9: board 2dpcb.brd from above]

Board: 2 copper layers, 170.2 x 111.2 mm, 103 parts (0 on the bottom side), 55 nets.

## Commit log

2025-04-04 add schematic
    [schematic.sch]
2025-04-04 add board
    [board.brd]
2025-04-06 last changes
    [board.brd, pcb.brd]
2025-04-11 fixed schematic issues
    [openbook_schematic.sch]
2025-04-11 fixed pcb issues
    [openbook_pcb.brd]
2025-04-11 fixed issues
    [2dpcb.brd, openbook_pcb.brd]

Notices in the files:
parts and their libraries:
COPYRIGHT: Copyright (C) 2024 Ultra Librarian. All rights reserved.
